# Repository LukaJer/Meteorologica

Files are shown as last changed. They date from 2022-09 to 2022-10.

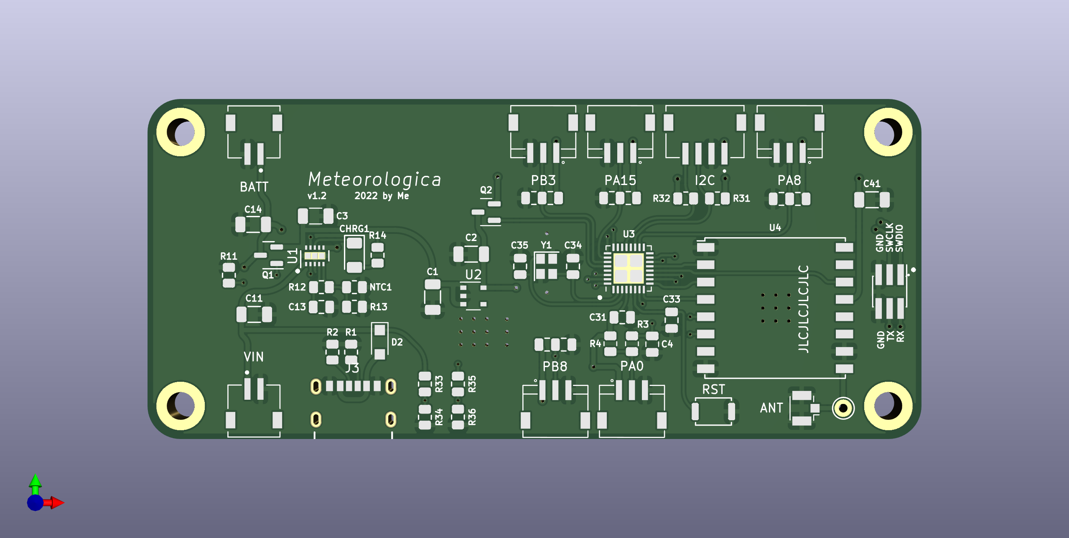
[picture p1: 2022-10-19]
Hardware/LoRaMini.png

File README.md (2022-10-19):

# Meteorologica

## A ultra-low-power, flexible Environment Monitioring Platform  
LoRaMini
### Hardware Desctiption:  
- uC: STM32G071
- LoRa Module: RFM95
- power management: BQ25060 (4.4V - 10.2V input)
- I2C 
- 5 GPIOs: (PA0 (int0), PA8, PA15, PB3, PB5)
- JST ZH 1.5mm connectors
- 1.27mm header for for programming and debugging (SWD+UART)
#### Detailed Description  
It's centered around a STM32G071 microcontroller and uses LoRa for efficient and longish range communication. Currently it sends to a custom Gateway which forwards the data to a MQTT server but the code can be easily adapted to use another LoRa infrastructure like The Things Network. The LoRa Module is a RFM95.  
A 18650 cell (other Li Ion batterys can be used too) is used for power  which can be charged from a powersource (4.4V - 10.2V) or via USB-C. The charging is done by a TI BQ25060 which offers semi-MPPT functionality. The uC can read the solar and battery voltage.  
There are 5 GPIOs available (PA0 (int0), PA8, PA15, PB3, PB5) and a I2C bus. All GPIOs have footprints for pull-up/-down resistors or capacitors and 3V3 and GND connections next to them. JST ZH 1.5mm connectors are used and a 1.27mm header is present for programming and debugging (SWD+UART). Each sensor can be either powered directly from 3V3 or a toggleable 3V3 bus . NOTE: the toggleable bus is implemented in Hardware but untested and has currently software support.

### Software Description:
The project is written in Arduino.  
Each Station has it's own name so multiple can be used on a single Gateway. 
The station wakes up in specified Intervalls (2min) and checks if any of the sensor values have changed, if so it sends the data as a JSON to the Gatway. The data is send every 10th wakeup no matter the values as a heartbeat. 
Currently
- Bosch BME280
- Sensiron SHT31
- Lacrosse TX23
- MaXIM DS18B20
- generic simple rain sensor
are implemented an can be enabled by uncommenting code.

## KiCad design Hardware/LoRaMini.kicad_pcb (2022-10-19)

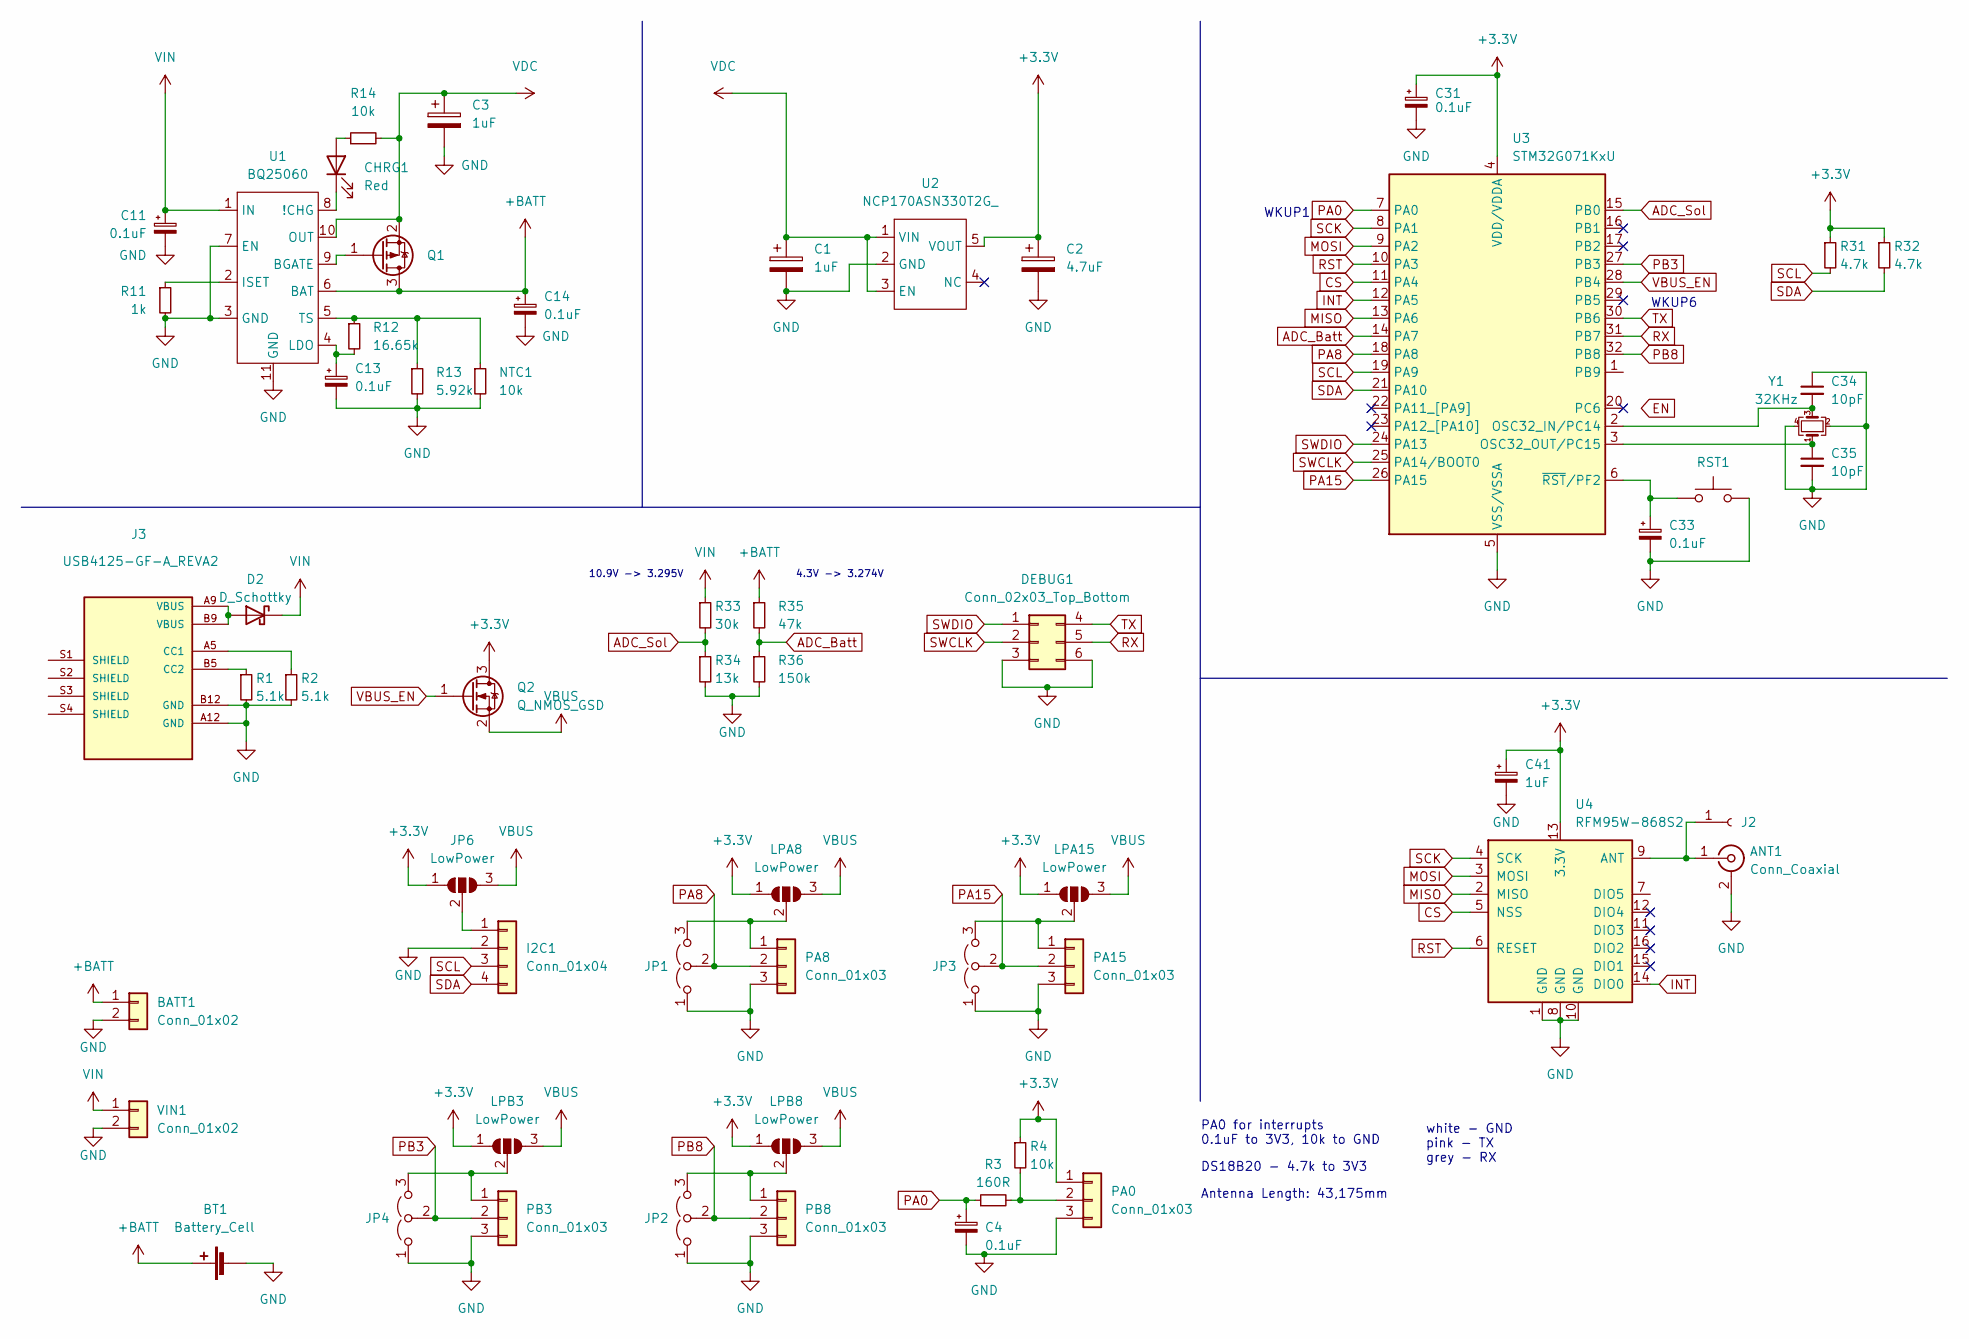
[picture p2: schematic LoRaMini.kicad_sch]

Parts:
ANT1: Conn_Coaxial; U.FL_Hirose_U.FL-R-SMT-1_Vertical
BATT1: Conn_01x02; JST_S2B-ZR-SM4A-TF(LF)(SN)
BT1: Battery_Cell; BatteryHolder_1x18650
C1, C3, C41: 1uF; C_1206_3216Metric
C2: 4.7uF; C_1206_3216Metric
C4, C13, C31, C33: 0.1uF; C_0805_2012Metric
C11, C14: 0.1uF; C_1206_3216Metric
C34, C35: 10pF; C_0805_2012Metric
CHRG1: Red; LED_1206_3216Metric
D2: D_Schottky; Nexperia_CFP3_SOD-123W
DEBUG1: Conn_02x03_Top_Bottom; PinHeader_2x03_P1.27mm_Vertical_SMD_My
I2C1: Conn_01x04; JST_S4B-ZR-SM4A-TF(LF)(SN)
J2: Conn_01x01_Female; Pin_D1.0mm_L10.0mm
J3: USB4125-GF-A_REVA2; GCT_USB4125-GF-A_REVA2; PARTREV Rev A2
JP1, JP2, JP3, JP4: Jumper_3_Open; Jumper_3_0805
JP6: LowPower; SolderJumper-3_P1.3mm_Open_Pad1.0x1.5mm
LPA8, LPA15: LowPower; SolderJumper-3_P1.3mm_Open_Pad1.0x1.5mm
LPB3, LPB8: LowPower; SolderJumper-3_P1.3mm_Open_Pad1.0x1.5mm
NTC1: 10k; R_0805_2012Metric
PA0, PA8, PA15: Conn_01x03; JST_S3B-ZR-SM4A-TF
PB3, PB8: Conn_01x03; JST_S3B-ZR-SM4A-TF
Q1: Q_PMOS_GSD; SOT-23
Q2: Q_NMOS_GSD; SOT-23
R1, R2: 5.1k; R_0805_2012Metric
R3: 160R; R_0805_2012Metric
R4, R14: 10k; R_0805_2012Metric
R11: 1k; R_0805_2012Metric
R12: 16.65k; R_0805_2012Metric
R13: 5.92k; R_0805_2012Metric
R31, R32: 4.7k; R_0805_2012Metric
R33: 30k; R_0805_2012Metric
R34: 13k; R_0805_2012Metric
R35: 47k; R_0805_2012Metric
R36: 150k; R_0805_2012Metric
RST1: SW_Push; SW_Push_SPST_NO_Alps_SKRK
U1: BQ25060; WSON-10-1EP_2x3mm_P0.5mm_EP0.84x2.4mm
U2: NCP170ASN330T2G_; TSOP-5_1.65x3.05mm_P0.95mm
U3: STM32G071KxU; UFQFPN-32-1EP_5x5mm_P0.5mm_EP3.5x3.5mm
U4: RFM95W-868S2; HOPERF_RFM9XW_SMD
VIN1: Conn_01x02; JST_S2B-ZR-SM4A-TF(LF)(SN)
Y1: 32KHz; Crystal_SMD_2520-4Pin_2.5x2.0mm

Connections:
+3V3: C2.1, C31.1, C41.1, JP6.1 (A), LPA8.1 (A), LPA15.1 (A), LPB3.1 (A), LPB8.1 (A), PA0.1, Q2.3 (D), R4.1, R31.1, R32.1, U2.5 (VOUT), U3.4 (VDD/VDDA), U4.13 (3.3V)
+BATT: BATT1.1, BT1.1 (+), C14.1, Q1.3 (D), R35.1, U1.6 (BAT); also elsewhere on the board
ADC_Batt: R35.2, R36.1, U3.14 (PA7)
ADC_Sol: R33.2, R34.1, U3.15 (PB0)
CS: U3.11 (PA4), U4.5 (NSS)
GND: ANT1.2 (Ext), BATT1.2, BT1.2 (-), C1.2, C2.2, C3.2, C4.2, C11.2, C13.2, C14.2, C31.2, C33.2, C34.1, C35.2, C41.2, DEBUG1.3, DEBUG1.6, I2C1.2, J3.A12 (GND), J3.B12 (GND), JP1.1 (A), JP2.1 (A), JP3.1 (A), JP4.1 (A), NTC1.2, PA0.3, PA8.3, PA15.3, PB3.3, PB8.3, R1.2, R2.2, R11.2, R13.2, R34.2, R36.2, RST1.2, U1.3 (GND), U1.7 (EN), U1.11 (GND), U2.2 (GND), U3.5 (VSS/VSSA), U3.33 (VSS/VSSA), U4.1 (GND), U4.8 (GND), U4.10 (GND), VIN1.2, Y1.2, Y1.4; also elsewhere on the board
INT: U3.12 (PA5), U4.14 (DIO0)
MISO: U3.13 (PA6), U4.2 (MISO)
MOSI: U3.9 (PA2), U4.3 (MOSI)
unnamed 9: ANT1.1 (In), J2.1, U4.9 (ANT); also elsewhere on the board
unnamed: C13.1, R12.2, U1.4 (LDO)
unnamed 11: C33.1, RST1.1, U3.6 (~RST/PF2); also elsewhere on the board
unnamed: C34.2, U3.2 (OSC32_IN/PC14), Y1.3
unnamed: C35.1, U3.3 (OSC32_OUT/PC15), Y1.1
unnamed: CHRG1.1 (K), U1.8 (!CHG)
unnamed: CHRG1.2 (A), R14.1
unnamed: D2.2 (A), J3.A9 (VBUS), J3.B9 (VBUS)
unnamed 17: I2C1.1, JP6.2 (C); also elsewhere on the board
unnamed: J3.A5 (CC1), R2.1
unnamed: J3.B5 (CC2), R1.1
unnamed: JP1.3 (B), LPA8.2 (C), PA8.1
unnamed: JP2.3 (B), LPB8.2 (C), PB8.1
unnamed: JP3.3 (B), LPA15.2 (C), PA15.1
unnamed: JP4.3 (B), LPB3.2 (C), PB3.1
unnamed: NTC1.1, R12.1, R13.1, U1.5 (TS)
unnamed: PA0.2, R3.2, R4.2
unnamed: Q1.1 (G), U1.9 (BGATE)
unnamed: R11.1, U1.2 (ISET)
PA0: C4.1, R3.1, U3.7 (PA0)
PA8: JP1.2 (C), PA8.2, U3.18 (PA8)
PA15: JP3.2 (C), PA15.2, U3.26 (PA15)
PB3: JP4.2 (C), PB3.2, U3.27 (PB3)
PB8: JP2.2 (C), PB8.2, U3.32 (PB8)
RST: U3.10 (PA3), U4.6 (RESET)
RX: DEBUG1.5, U3.31 (PB7)
SCK: U3.8 (PA1), U4.4 (SCK)
SCL: I2C1.3, R31.2, U3.19 (PA9); also elsewhere on the board
SDA: I2C1.4, R32.2, U3.21 (PA10); also elsewhere on the board
SWCLK: DEBUG1.2, U3.25 (PA14/BOOT0)
SWDIO: DEBUG1.1, U3.24 (PA13)
TX: DEBUG1.4, U3.30 (PB6)
VBUS: JP6.3 (B), LPA8.3 (B), LPA15.3 (B), LPB3.3 (B), LPB8.3 (B), Q2.2 (S)
VBUS_EN: Q2.1 (G), U3.28 (PB4)
VDC: C1.1, C3.1, Q1.2 (S), R14.2, U1.10 (OUT), U2.1 (VIN), U2.3 (EN)
VDD: C11.1, D2.1 (K), R33.1, U1.1 (IN), VIN1.1; also elsewhere on the board

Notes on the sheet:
DS18B20 - 4.7k to 3V3
4.3V -> 3.274V
Antenna Length: 43,175mm
PA0 for interrupts 0.1uF to 3V3, 10k to GND
10.9V -> 3.295V
white - GND pink - TX grey - RX
WKUP6
WKUP1

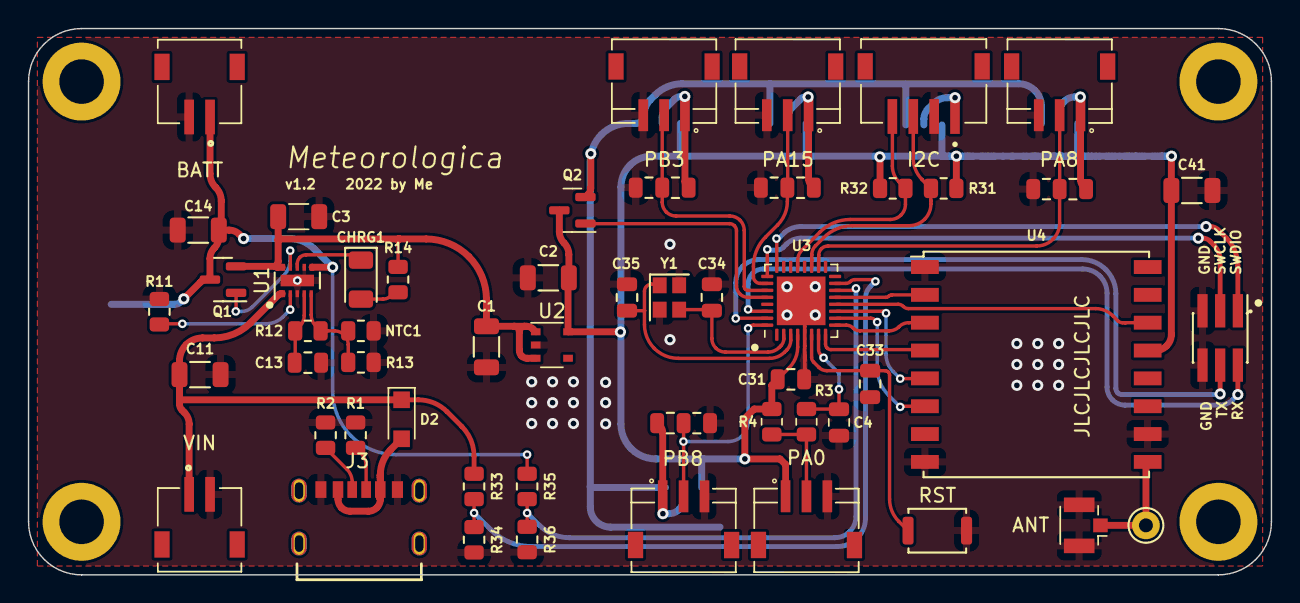
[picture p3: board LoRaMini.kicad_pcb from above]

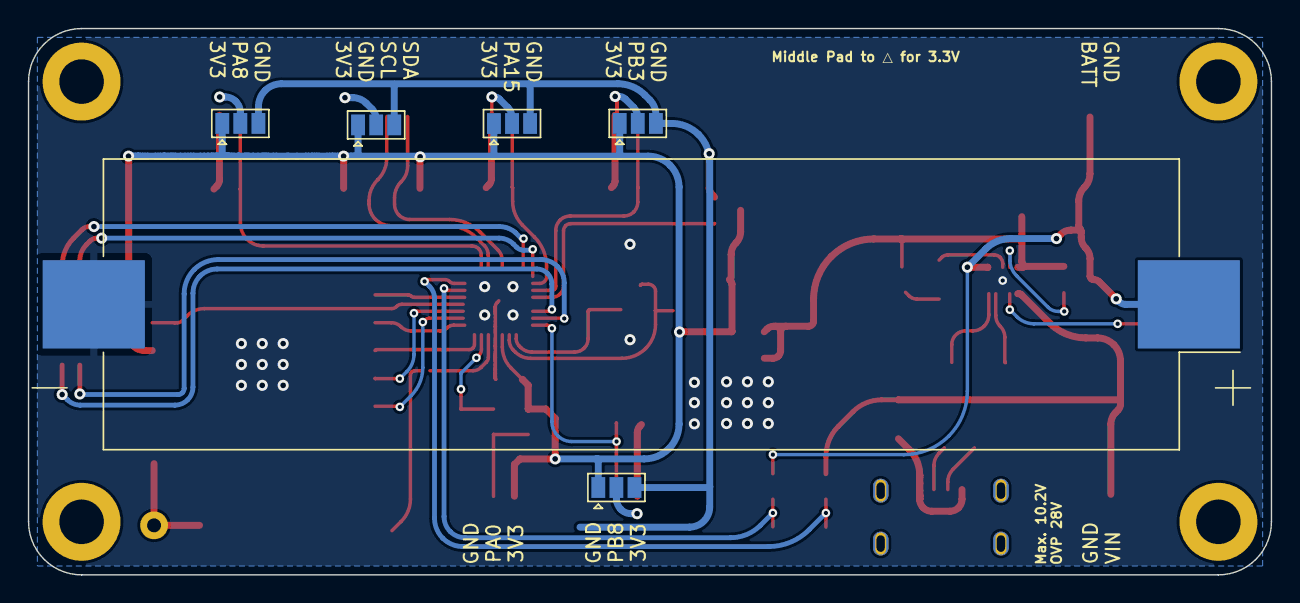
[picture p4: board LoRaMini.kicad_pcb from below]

Board: 2 copper layers, 89.3 x 39.2 mm, 59 parts (6 on the bottom side), 45 nets.

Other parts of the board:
ANT: Conn_Coaxial; U.FL_Hirose_U.FL-R-SMT-1_Vertical
BATT: Conn_01x02; JST_S2B-ZR-SM4A-TF(LF)(SN)
I2C: Conn_01x04; JST_S4B-ZR-SM4A-TF(LF)(SN)
RST: SW_Push; SW_Push_SPST_NO_Alps_SKRK
VIN: Conn_01x02; JST_S2B-ZR-SM4A-TF(LF)(SN)

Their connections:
+BATT: BATT.1; also elsewhere on the board
GND: ANT.2 (Ext), BATT.2, I2C.2, RST.2, VIN.2; also elsewhere on the board
unnamed 9: ANT.1 (In); also elsewhere on the board
unnamed 11: RST.1; also elsewhere on the board
unnamed 17: I2C.1; also elsewhere on the board
SCL: I2C.3; also elsewhere on the board
SDA: I2C.4; also elsewhere on the board
VDD: VIN.1; also elsewhere on the board

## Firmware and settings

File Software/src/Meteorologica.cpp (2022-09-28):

#include <RH_RF95.h>
#include <Arduino.h>
#include <RHEncryptedDriver.h>
#include <Speck.h>
#include <Wire.h>
#include <ArduinoJson.h>
#include <LaCrosse_TX23.h>
#include "STM32LowPower.h"

// General Pin Definitions
#define RFM95_RST PA3
#define RFM95_CS PA4
#define RFM95_INT PA5
#define MISO PA6
#define MOSI PA2
#define SCK PA1
#define I2C_SDA PA10
#define I2C_SCL PA9

#define F_CPU 16000000

// Uncomment used Sensors:
//#define WIND
//#define BME280
//#define RMTSENS
//#define SHT31
#define RAIN

// Radiohead RF95 Driver
RH_RF95 rf95(RFM95_CS, RFM95_INT);			// Instanciate a LoRa driver
Speck myCipher;								// Instanciate a Speck block ciphering
RHEncryptedDriver myDriver(rf95, myCipher); // Instantiate the driver with those two

// Bosch BME280 Definition
#ifdef BME280
#include <Adafruit_Sensor.h>
#include <Adafruit_BME280.h>
#define SEALEVELPRESSURE_HPA (1013.25)
Adafruit_BME280 bme;
float Temp, Hum, Press;

#endif // BME280

// Sensorion SHT31 Definition
#ifdef SHT31
#include "Adafruit_SHT31.h"
Adafruit_SHT31 sht31 = Adafruit_SHT31();
float Temp1, Hum1;
#endif // SHT31

// MaXIM DS18B20 Definition
#ifdef RMTSENS
#define RemoteTempPin PA15
#include <OneWire.h>
#include <DallasTemperature.h>
OneWire oneWire(RemoteTempPin);
DallasTemperature RemoteSensor(&oneWire);
#endif // RMTSENS

// LaCrosse TX23 Definition
#ifdef WIND
#define Wind_Pin PB8
LaCrosse_TX23 anemometer = LaCrosse_TX23(Wind_Pin);
float speed, speed_old;
int dir, dir_old;
#endif // WIND

// Generic Rain Interrupt Sensor Definition
#ifdef RAIN
#define rainPin PA0 // fixed!!
volatile uint8_t rainPulses = 0;
void rainfct();
#endif // RAIN

float frequency = 868.0;																// LoRa Frequency
unsigned char encryptkey[16] = {1, 2, 3, 4, 5, 6, 7, 8, 9, 10, 11, 12, 13, 14, 15, 16}; // The very secret key
String name = "WSDev";																	// Name of the Weather Station
uint8_t HWMessageLen, nrWakeup = 0;
DynamicJsonDocument payload(512);			  // JSON Definition (might be shortened)
int SendInterval_LP = 600, SendInterval = 120; //  (Low Power) Send Intervall in Seconds
int ValChng = 0;							  // Tracks if values have changed
float VBatt, VSol;

void setup()
{
	// Set UART Pins
	Serial.setRx(PB7);
	Serial.setTx(PB6);
	Serial.begin(9600);

	payload["Name"] = name;
	Serial.println("WeatherLoRa Client: " + name);
	delay(100);

	// Set I2C Pins
	Wire.setSDA(I2C_SDA);
	Wire.setSCL(I2C_SCL);
	Wire.begin();

// Sensor Initalisation
#ifdef BME280
	unsigned status;
	status = bme.begin(0x76);
	if (!status)
	{
		Serial.println("Could not find a valid BME280 sensor, check wiring, address, sensor ID!");
		Serial.print("SensorID was: 0x");
		Serial.println(bme.sensorID(), 16);
		Serial.print("        ID of 0xFF probably means a bad address, a BMP 180 or BMP 085\n");
		Serial.print("   ID of 0x56-0x58 represents a BMP 280,\n");
		Serial.print("        ID of 0x60 represents a BME 280.\n");
		Serial.print("        ID of 0x61 represents a BME 680.\n");
		while (1)
			delay(10);
	}
#endif // BME280

#ifdef SHT31
	if (!sht31.begin(0x44))
	{ // Set to 0x45 for alternate i2c addr
		Serial.println("Couldn't find SHT31");
		while (1)
			delay(1);
	}
#endif // SHT31

#ifdef RMTSENS
	RemoteSensor.begin();
#endif // RMTSENS

	// Set SPI Pins
	SPI.setMISO(MISO);
	SPI.setMOSI(MOSI);
	SPI.setSCLK(SCK);
	delay(10);

	// LoRa Initalisation
	if (!rf95.init())
	{
		Serial.println("LoRa init failed");
		while (1) // Halt Startup if RF95 not found
			delay(1);
	}
	rf95.setFrequency(frequency);
	rf95.setTxPower(13);
	myCipher.setKey(encryptkey, sizeof(encryptkey));

	LowPower.begin();
// Enable Rain Interrupt
#ifdef RAIN
	pinMode(rainPin, INPUT_FLOATING);
	LowPower.attachInterruptWakeup(rainPin, rainfct, RISING, DEEP_SLEEP_MODE);
#endif // RAIN

	Serial.println("Setup completed");
	delay(1000);
}

void loop()
{

	float buffer = 0;

	delay(50);
	Serial.print("Wake-Up Nr: ");
	Serial.println(nrWakeup);
	// Keeping Track of #Wakeups
	nrWakeup++;
	// Data gets send every 10th wake-up independent wether data has changed: Heartbeat
	if (!(nrWakeup % 10))
	{
		ValChng = 1;
	}
	delay(50);
	Serial.print("Rainpulse: ");
	Serial.println(rainPulses);
// Read Wind Data
#ifdef WIND
	if (anemometer.read(speed, dir))
	{
		Serial.println("Wind found");
		/* Wind Data gets only sent if speed is greater 0 and
		Speedchange > 0.5 or
		ValChng = 1 or
		Direction Change > 0.5
		*/
		if (abs(speed_old - speed) > 0.5 || ValChng || ((abs(dir_old - dir) > 0.5) && speed > 0))
		{
			ValChng = 1;
			payload["Speed"] = speed;
			speed_old = speed;
			payload["Dir"] = dir * 22.5;
			dir_old = dir;
		}
	}
#endif // WIND

// Read BME280 Data
#ifdef BME280
	bme.takeForcedMeasurement();
	/* BEM280 Data gets only sent if
	Temperaturechange > 0.5°C or
	Humiditychange > 5%
	*/
	buffer = bme.readTemperature() / 1.0;
	if (abs(Temp - buffer) > 0.5 || ValChng)
	{
		ValChng = 1;
		payload["Temp"] = buffer;
		Temp = buffer;
	}
	buffer = roundf(bme.readHumidity() * 100) / 100;
	if (abs(Hum - buffer) > 5 || ValChng)
	{
		ValChng = 1;
		payload["Hum"] = buffer;
		Hum = buffer;
	}

	buffer = roundf(bme.readPressure()) / 100;
	if (abs(Press - buffer) > 0.5 || ValChng)
	{
		ValChng = 1;
		payload["Press"] = buffer;
		Press = buffer;
	}
#endif // BME280

// Read SHT 31 Data
#ifdef SHT31
	/* SHT31 Data gets only sent if
	Temperaturechange > 0.5°C or
	Humiditychange > 5%
	*/
	buffer = sht31.readTemperature();
	if (abs(Temp1 - buffer) > 0.5 || ValChng)
	{
		ValChng = 1;
		payload["Temp1"] = buffer;
		Temp1 = buffer;
	}

	buffer = sht31.readHumidity();
	if (abs(Hum1 - buffer) > 5 || ValChng)
	{
		ValChng = 1;
		payload["Hum1"] = buffer;
		Hum1 = buffer;
	}
#endif // SHT31

// Read Remote Sensor Data
#ifdef RMTSENS
	float RemoteTemp(NAN);
	RemoteSensor.requestTemperatures();
	RemoteTemp = RemoteSensor.getTempCByIndex(0);
	if (RemoteTemp != -127)
	{
		payload["RmtTmp"] = RemoteTemp;
	}
#endif // RMTSENS

#ifdef RAIN
	payload["RainC"] = rainPulses;
#endif // RAIN

	if (!ValChng)
	{
		// Don't send anything if no new Data or not a 10th wakeup
		Serial.println("No new Data, back to zzzz");
		delay(50);

		LowPower.deepSleep(SendInterval * 1000);
	}
	else
	{
		rainPulses = 0; // Reset RainPulses

		// Read Battery and Solar Voltages (8bit)
		VBatt = analogRead(PA7) * 4.3 / 1024;
		VSol = analogRead(PB0) * 10.9 / 1024;
		payload["VBatt"] = trunc(VBatt * 100) / 100;
		if (floor(VSol) > 0)
		{
			payload["VSol"] = trunc(VSol * 100) / 100;
		}

		size_t len = 32;
		char message[256]; // SerializedJSON, replace with len?
		len = payload.memoryUsage();
		Serial.println(len);
		serializeJson(payload, message); // Create String (Char Array) from JSON
		uint8_t data[len + 1]; // RFM95 input

		for (uint8_t i = 0; i <= len; i++) // Copy and Typecast Data from JSONString to uint8_t Array
		{
			data[i] = (uint8_t)message[i];
		}
		data[len + 1] = '\0';
		myDriver.send(data, sizeof(data)); // Send out ID + Sensor data to LoRa gateway
		Serial.print("Sent: ");
		delay(50);
		Serial.println((char *)&data);
		delay(50);
		rf95.sleep(); // Put RF95 to sleep
		ValChng = 0;
		delay(100);
		// Check if Battery is above 3V, if not use LowPower Intervall for Wakups, current not used!
		if (VBatt > 3.0)
			LowPower.deepSleep(SendInterval * 1000);
		else
		{
			LowPower.deepSleep(SendInterval_LP * 1000);
			ValChng = 1;
		}
	}
}


/* 
Rain Interrupt triggers this function
Increment Number of Rain Pulses an go back to Sleep
*/
#ifdef RAIN
void rainfct()
{
	rainPulses++;
	delay(50);
	LowPower.deepSleep();
}
#endif // RAIN

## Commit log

2022-09-28 HW init
    [LoRaMini-B_Cu.gbr, LoRaMini-B_Mask.gbr, LoRaMini-B_Paste.gbr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]
2022-10-19 fixed PA0
    [LoRaMini.kicad_pcb, LoRaMini.kicad_sch]
